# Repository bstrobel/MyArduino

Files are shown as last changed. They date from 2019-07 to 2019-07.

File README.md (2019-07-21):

# MyArduino
PCB to get my stock pile of 328s used as Arduino

Idee: Kleines generisches PCB bei Elecrow bestellten, um meine 328 einfach verbauen oder auf Steckbrett verwenden zu können.
- Größe um in direkt in kleines, günstiges Gehäuse verbaut werden zu können, das es bei Reichelt oder Conrad gibt
	- Gehäuse bei R heraussuchen, wenn Mindestgröße feststeht
- Pin Header mit Belegung und Bezeichnung wie bei Arduino, aber nicht notwendigerweise so angeordnet, dass Arduino Shields darauf passen. Aber eventuell so, dass Einsatz kleiner Shields für SD-Karten oder Sensoren nicht blockiert wird.
- Pin Header so anordnen, dass Verwendung auf Steckbrett möglich ist
- Stromversorgung:
	- Optionale Bestückung mit LM317 inkl. Justier-Rs und Block-Cs
	- auch MCP1702 (LDO 5v) Regler -> Achtung: nicht pinkompatibel mit 78L05!
	- Stromversorgungsheader für direkte Versorgung oder an Regler-IC
- ICP Header mit Standardbelegung
- Resettaster
- Arduino-LED an Port 13 vorsehen, muss ja nicht bestückt werden.
- Quarzbestückung vorsehen
	- aber Ports auch herausführen
- AREF-Cap: https://www.avrfreaks.net/forum/capacitor-aref-atmega328

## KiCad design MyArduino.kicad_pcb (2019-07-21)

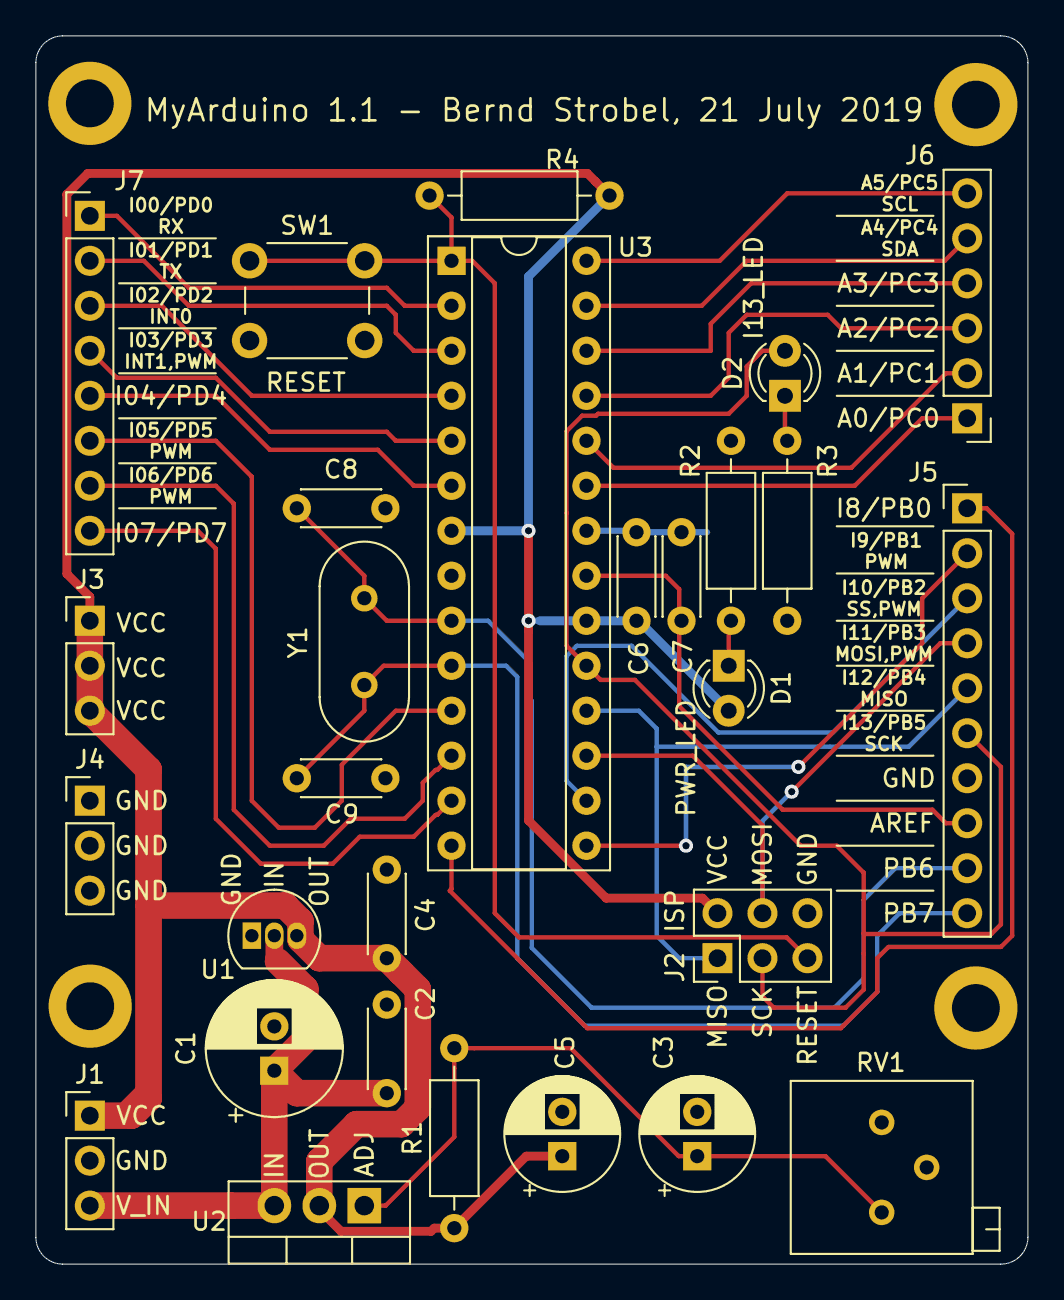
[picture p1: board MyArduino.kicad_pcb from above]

Board: 2 copper layers, 56.0 x 69.3 mm, 32 parts (0 on the bottom side), 30 nets.

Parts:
C1: 100u; CP_Radial_D7.5mm_P2.50mm
C2, C4, C6: 100n; C_Disc_D4.3mm_W1.9mm_P5.00mm
C3: 10u; CP_Radial_D6.3mm_P2.50mm
C5: 22u; CP_Radial_D6.3mm_P2.50mm
C7: 10n; C_Disc_D4.3mm_W1.9mm_P5.00mm
C8, C9: 22p; C_Disc_D4.3mm_W1.9mm_P5.00mm
D1, D2: LED; LED_D3.0mm
J1: PWR; PinHeader_1x03_P2.54mm_Vertical
J2: ISP; PinHeader_2x03_P2.54mm_Vertical
J3: VCC; PinHeader_1x03_P2.54mm_Vertical
J4: GND; PinHeader_1x03_P2.54mm_Vertical
J5: IOH; PinHeader_1x10_P2.54mm_Vertical
J6: AD; PinHeader_1x06_P2.54mm_Vertical
J7: IOL; PinHeader_1x08_P2.54mm_Vertical
J8, J9, J10, J11: MountingHole_2.7mm_M2.5_DIN965_Pad
R1: 240R; R_Axial_DIN0207_L6.3mm_D2.5mm_P10.16mm_Horizontal
R2, R3: 470R; R_Axial_DIN0207_L6.3mm_D2.5mm_P10.16mm_Horizontal
R4: 10k; R_Axial_DIN0207_L6.3mm_D2.5mm_P10.16mm_Horizontal
RV1: 5k; Potentiometer_Bourns_3296P_Horizontal
SW1: SW_Push; SW_PUSH_6mm_H5mm
U1: MCP1700-5002E_TO92; TO-92_Inline
U2: LM317_TO220; TO-220-3_Vertical
U3: ATmega328P-PU; DIP-28_W7.62mm_Socket
Y1: 16MHz; Crystal_HC18-U_Vertical

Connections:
/AD0: J6.1, U3.23
/AD1: J6.2, U3.24
/AD2: J6.3, U3.25
/AD3: J6.4, U3.26
/AD4: J6.5, U3.27
/AD5: J6.6, U3.28
/AREF: C7.1, J5.8, U3.21
/IO0: J7.1, U3.2
/IO1: J7.2, U3.3
/IO2: J7.3, U3.4
/IO3: J7.4, U3.5
/IO4: J7.5, U3.6
/IO5: J7.6, U3.11
/IO6: J7.7, U3.12
/IO7: J7.8, U3.13
/IO8: J5.1, U3.14
/IO9: J5.2, U3.15
/MISO: J2.1, J5.5, U3.18
/MOSI: J2.4, J5.4, U3.17
/RESET: J2.5, R4.2, SW1.1, U3.1
/SCK: D2.2, J2.3, J5.6, U3.19
/SS: J5.3, U3.16
/V_UNREG: C1.1, C2.1, J1.3, U1.2, U2.3
/XTAL1_PB6: C8.1, J5.9, U3.9, Y1.1
/XTAL2_PB7: C9.1, J5.10, U3.10, Y1.2
GND: C1.2, C2.2, C3.2, C4.2, C5.2, C6.2, C7.2, C8.2, C9.2, J1.2, J2.6, J4.1, J4.2, J4.3, J5.7, J8.1, J9.1, J10.1, J11.1, R2.2, R3.2, RV1.2, RV1.3, SW1.2, U1.1, U3.8, U3.22
unnamed: C3.1, R1.2, RV1.1, U2.1
unnamed: D1.1, R2.1
unnamed: D2.1, R3.1
VCC: C4.1, C5.1, C6.1, D1.2, J1.1, J2.2, J3.1, J3.2, J3.3, R1.1, R4.1, U1.3, U2.2, U3.7, U3.20

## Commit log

2019-07-21 Version 1.0
    Ordered 5 pcs @ Elecrow today
    [MyArduino.kicad_pcb, MyArduino.sch]
2019-07-21 Improved routing and power traces width
    Version 1.1
    [MyArduino-B_Cu.gbr, MyArduino-B_Mask.gbr, MyArduino-B_Paste.gbr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]
